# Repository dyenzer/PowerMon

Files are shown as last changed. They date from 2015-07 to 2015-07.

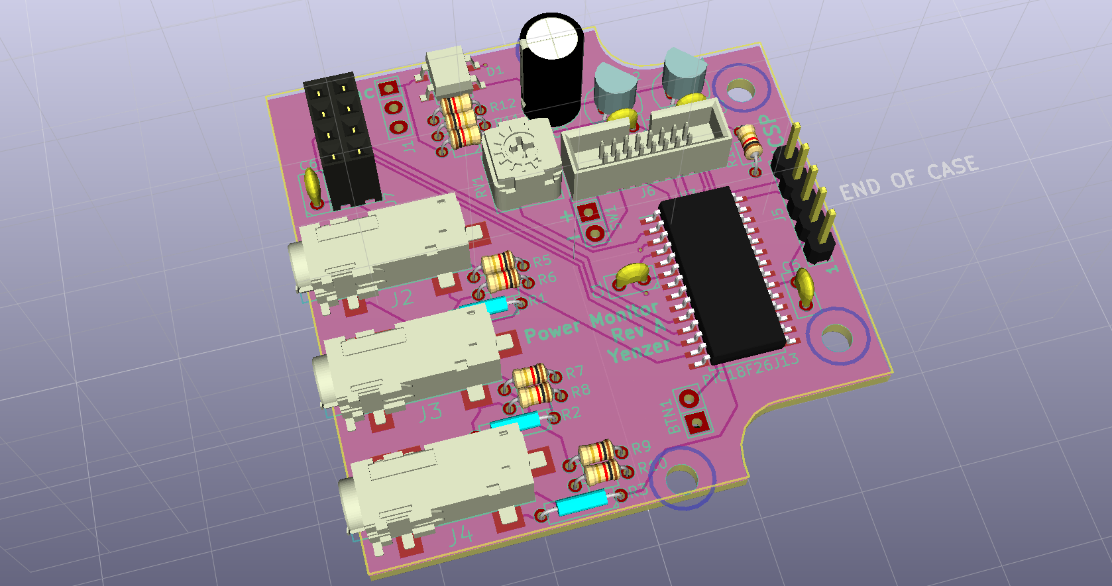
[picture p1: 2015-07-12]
Schematic/Power Monitor 3d.png

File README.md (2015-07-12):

#Power Monitor
Non-intrusive way to monitor the power consumed in your home

This repository contains the schematics and code for this project.
More details at https://hackaday.io/project/6700-home-power-usage-monitor
  
#Repository Contents
* **/Schematic** - Circuit diagram and PCB layout
  
#License Information
This project is released under <a href = "https://creativecommons.org/licenses/by-sa/4.0/">CC BY-SA 4.0</a>  
Original Design by Drew Yenzer

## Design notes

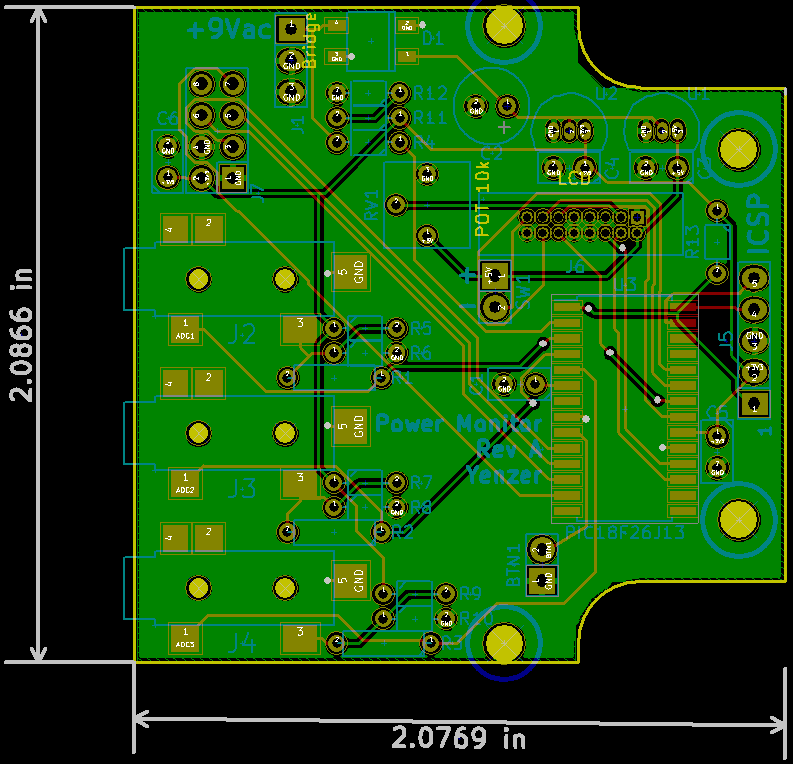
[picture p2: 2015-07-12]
Schematic/Board Layout.png

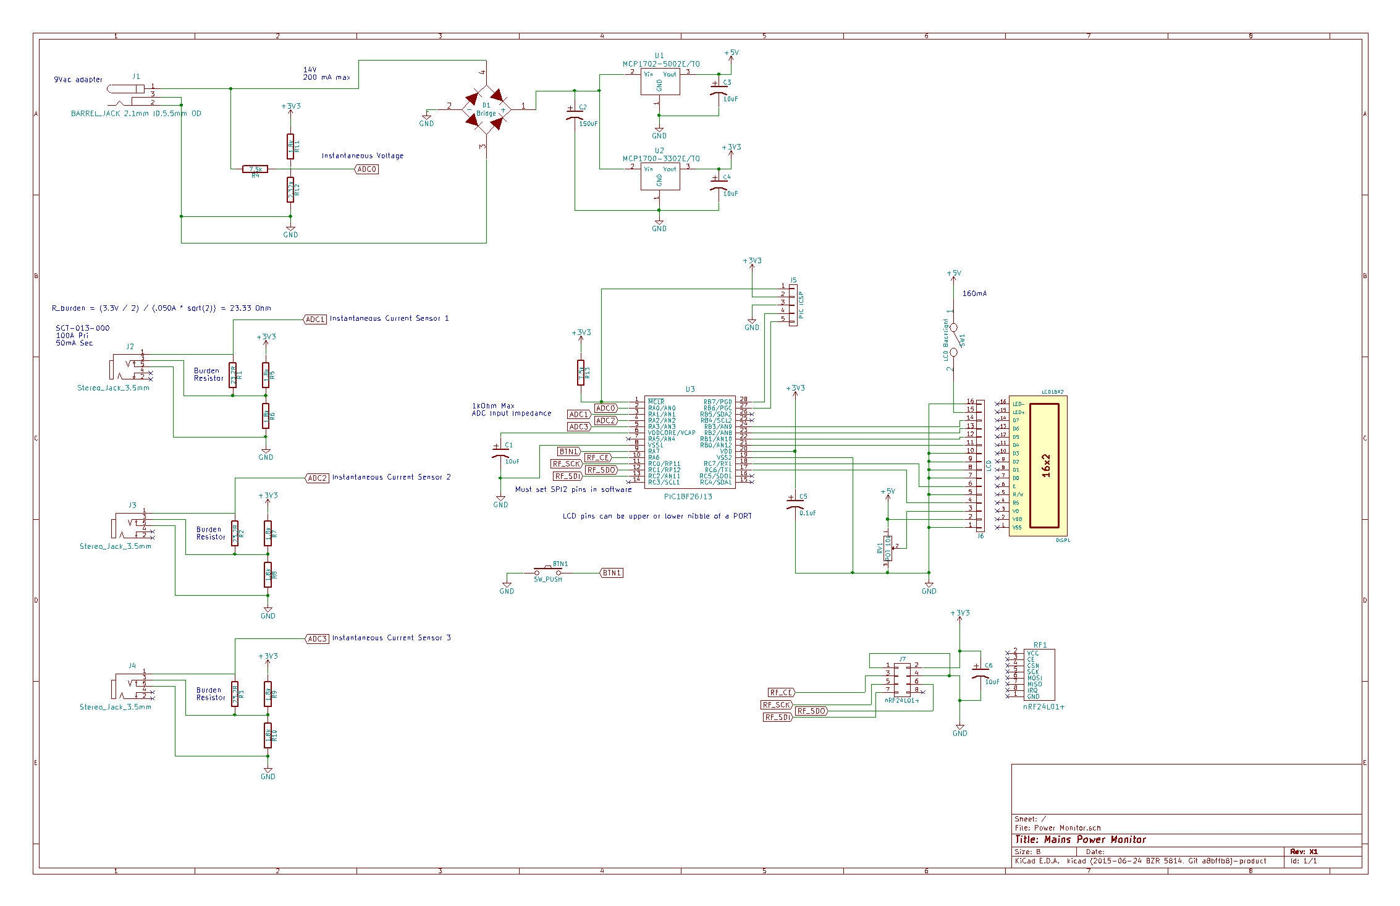
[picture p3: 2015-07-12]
Schematic/Schematic.png

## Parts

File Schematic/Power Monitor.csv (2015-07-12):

Source: | C:/Users/Drew/Desktop/Projects/Power Monitor/Schematic/Power Monitor.sch
Date: | 6/27/2015 16:34
Tool: | Eeschema (2015-06-24 BZR 5814, Git a8bffb8)-product
Generator: | C:\KiCad\bin\scripting\plugins\bom-in-python\bom_csv_grouped_by_value.py
Component Count: | 34
Individual Components:
Item | Qty | Reference(s) | Value | LibPart | Footprint | Datasheet
 |  | C1 | 10uF | device:CP1
 |  | C2 | 150uF | device:CP1
 |  | C3 | 10uF | device:CP1
 |  | C4 | 10uF | device:CP1
 |  | C5 | 0.1uF | device:CP1
 |  | C6 | 10uF | device:CP1
 |  | D1 | Bridge | custom:Bridge
 |  | DISP1 | LCD16X2 | display:LCD16X2 | WC1602A
 |  | J1 | BARREL_JACK 2.1mm ID,5.5mm OD | conn:BARREL_JACK
 |  | J2 | Stereo_Jack_3.5mm | custom:Stereo_Jack_3.5mm
 |  | J3 | Stereo_Jack_3.5mm | custom:Stereo_Jack_3.5mm
 |  | J4 | Stereo_Jack_3.5mm | custom:Stereo_Jack_3.5mm
 |  | J5 | PIC ICSP | conn:CONN_01X05
 |  | J6 | LCD | conn:CONN_01X16
 |  | J7 | nRF24L01+ | conn:CONN_02X04
 |  | R1 | 23.2R | device:R
 |  | R10 | 1.75k | device:R
 |  | R11 | 1.75k | device:R
 |  | R12 | 2.32k | device:R
 |  | R13 | 7.5k | device:R
 |  | R2 | 23.2R | device:R
 |  | R3 | 23.2R | device:R
 |  | R4 | 7.5k | device:R
 |  | R5 | 1.75k | device:R
 |  | R6 | 1.75k | device:R
 |  | R7 | 1.75k | device:R
 |  | R8 | 1.75k | device:R
 |  | R9 | 1.75k | device:R
 |  | RF1 | nRF24L01+ | custom:nRF24L01+
 |  | RV1 | POT 10k | device:POT
 |  | SW1 | LCD Backlight | device:SPST
 |  | U1 | MCP1702-5002E/TO | custom:MCP1700
 |  | U2 | MCP1700-3302E/TO | custom:MCP1700
 |  | U3 | PIC18F26J13 | custom:PIC18F2XJ13
Collated Components:
Item | Qty | Reference(s) | Value | LibPart | Footprint | Datasheet
1 | 4 | C1, C3, C4, C6 | 10uF | device:CP1
2 | 1 | C2 | 150uF | device:CP1
3 | 1 | C5 | 0.1uF | device:CP1
4 | 1 | D1 | Bridge | custom:Bridge
5 | 1 | DISP1 | LCD16X2 | display:LCD16X2 | WC1602A
6 | 1 | J1 | BARREL_JACK 2.1mm ID,5.5mm OD | conn:BARREL_JACK
7 | 3 | J2, J3, J4 | Stereo_Jack_3.5mm | custom:Stereo_Jack_3.5mm
8 | 1 | J5 | PIC ICSP | conn:CONN_01X05
9 | 1 | J6 | LCD | conn:CONN_01X16
10 | 1 | J7 | nRF24L01+ | conn:CONN_02X04
11 | 3 | R1, R2, R3 | 23.2R | device:R
12 | 7 | R10, R11, R5, R6, R7, R8, R9 | 1.75k | device:R
13 | 1 | R12 | 2.32k | device:R
14 | 2 | R13, R4 | 7.5k | device:R
15 | 1 | RF1 | nRF24L01+ | custom:nRF24L01+
16 | 1 | RV1 | POT 10k | device:POT
17 | 1 | SW1 | LCD Backlight | device:SPST
18 | 1 | U1 | MCP1702-5002E/TO | custom:MCP1700
19 | 1 | U2 | MCP1700-3302E/TO | custom:MCP1700
20 | 1 | U3 | PIC18F26J13 | custom:PIC18F2XJ13

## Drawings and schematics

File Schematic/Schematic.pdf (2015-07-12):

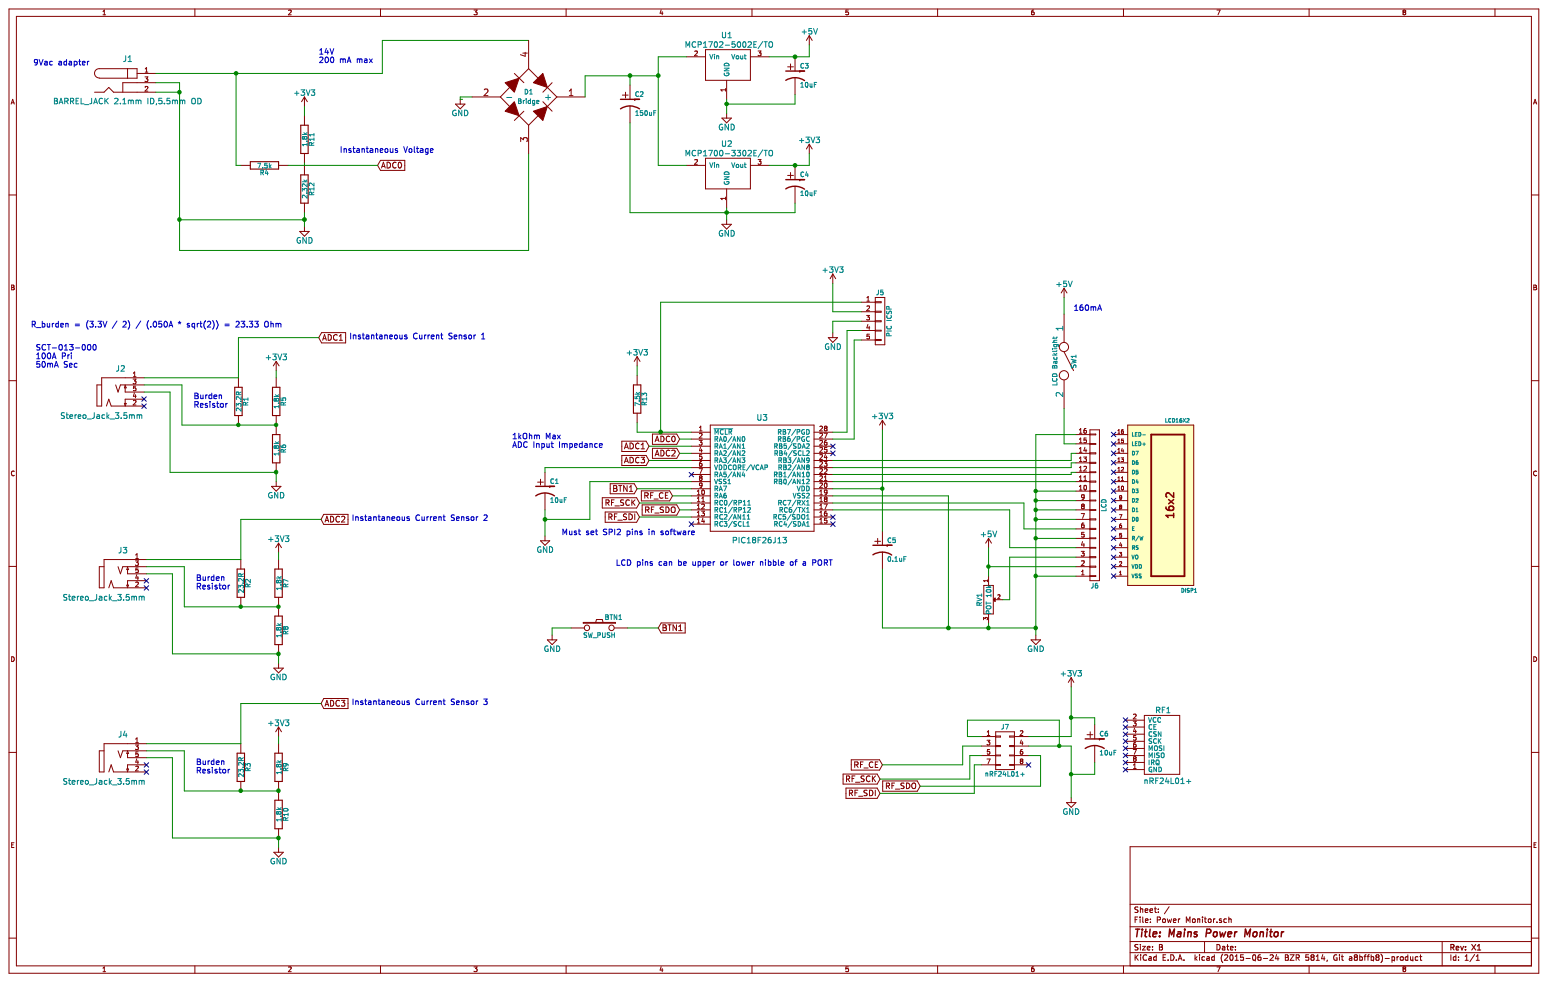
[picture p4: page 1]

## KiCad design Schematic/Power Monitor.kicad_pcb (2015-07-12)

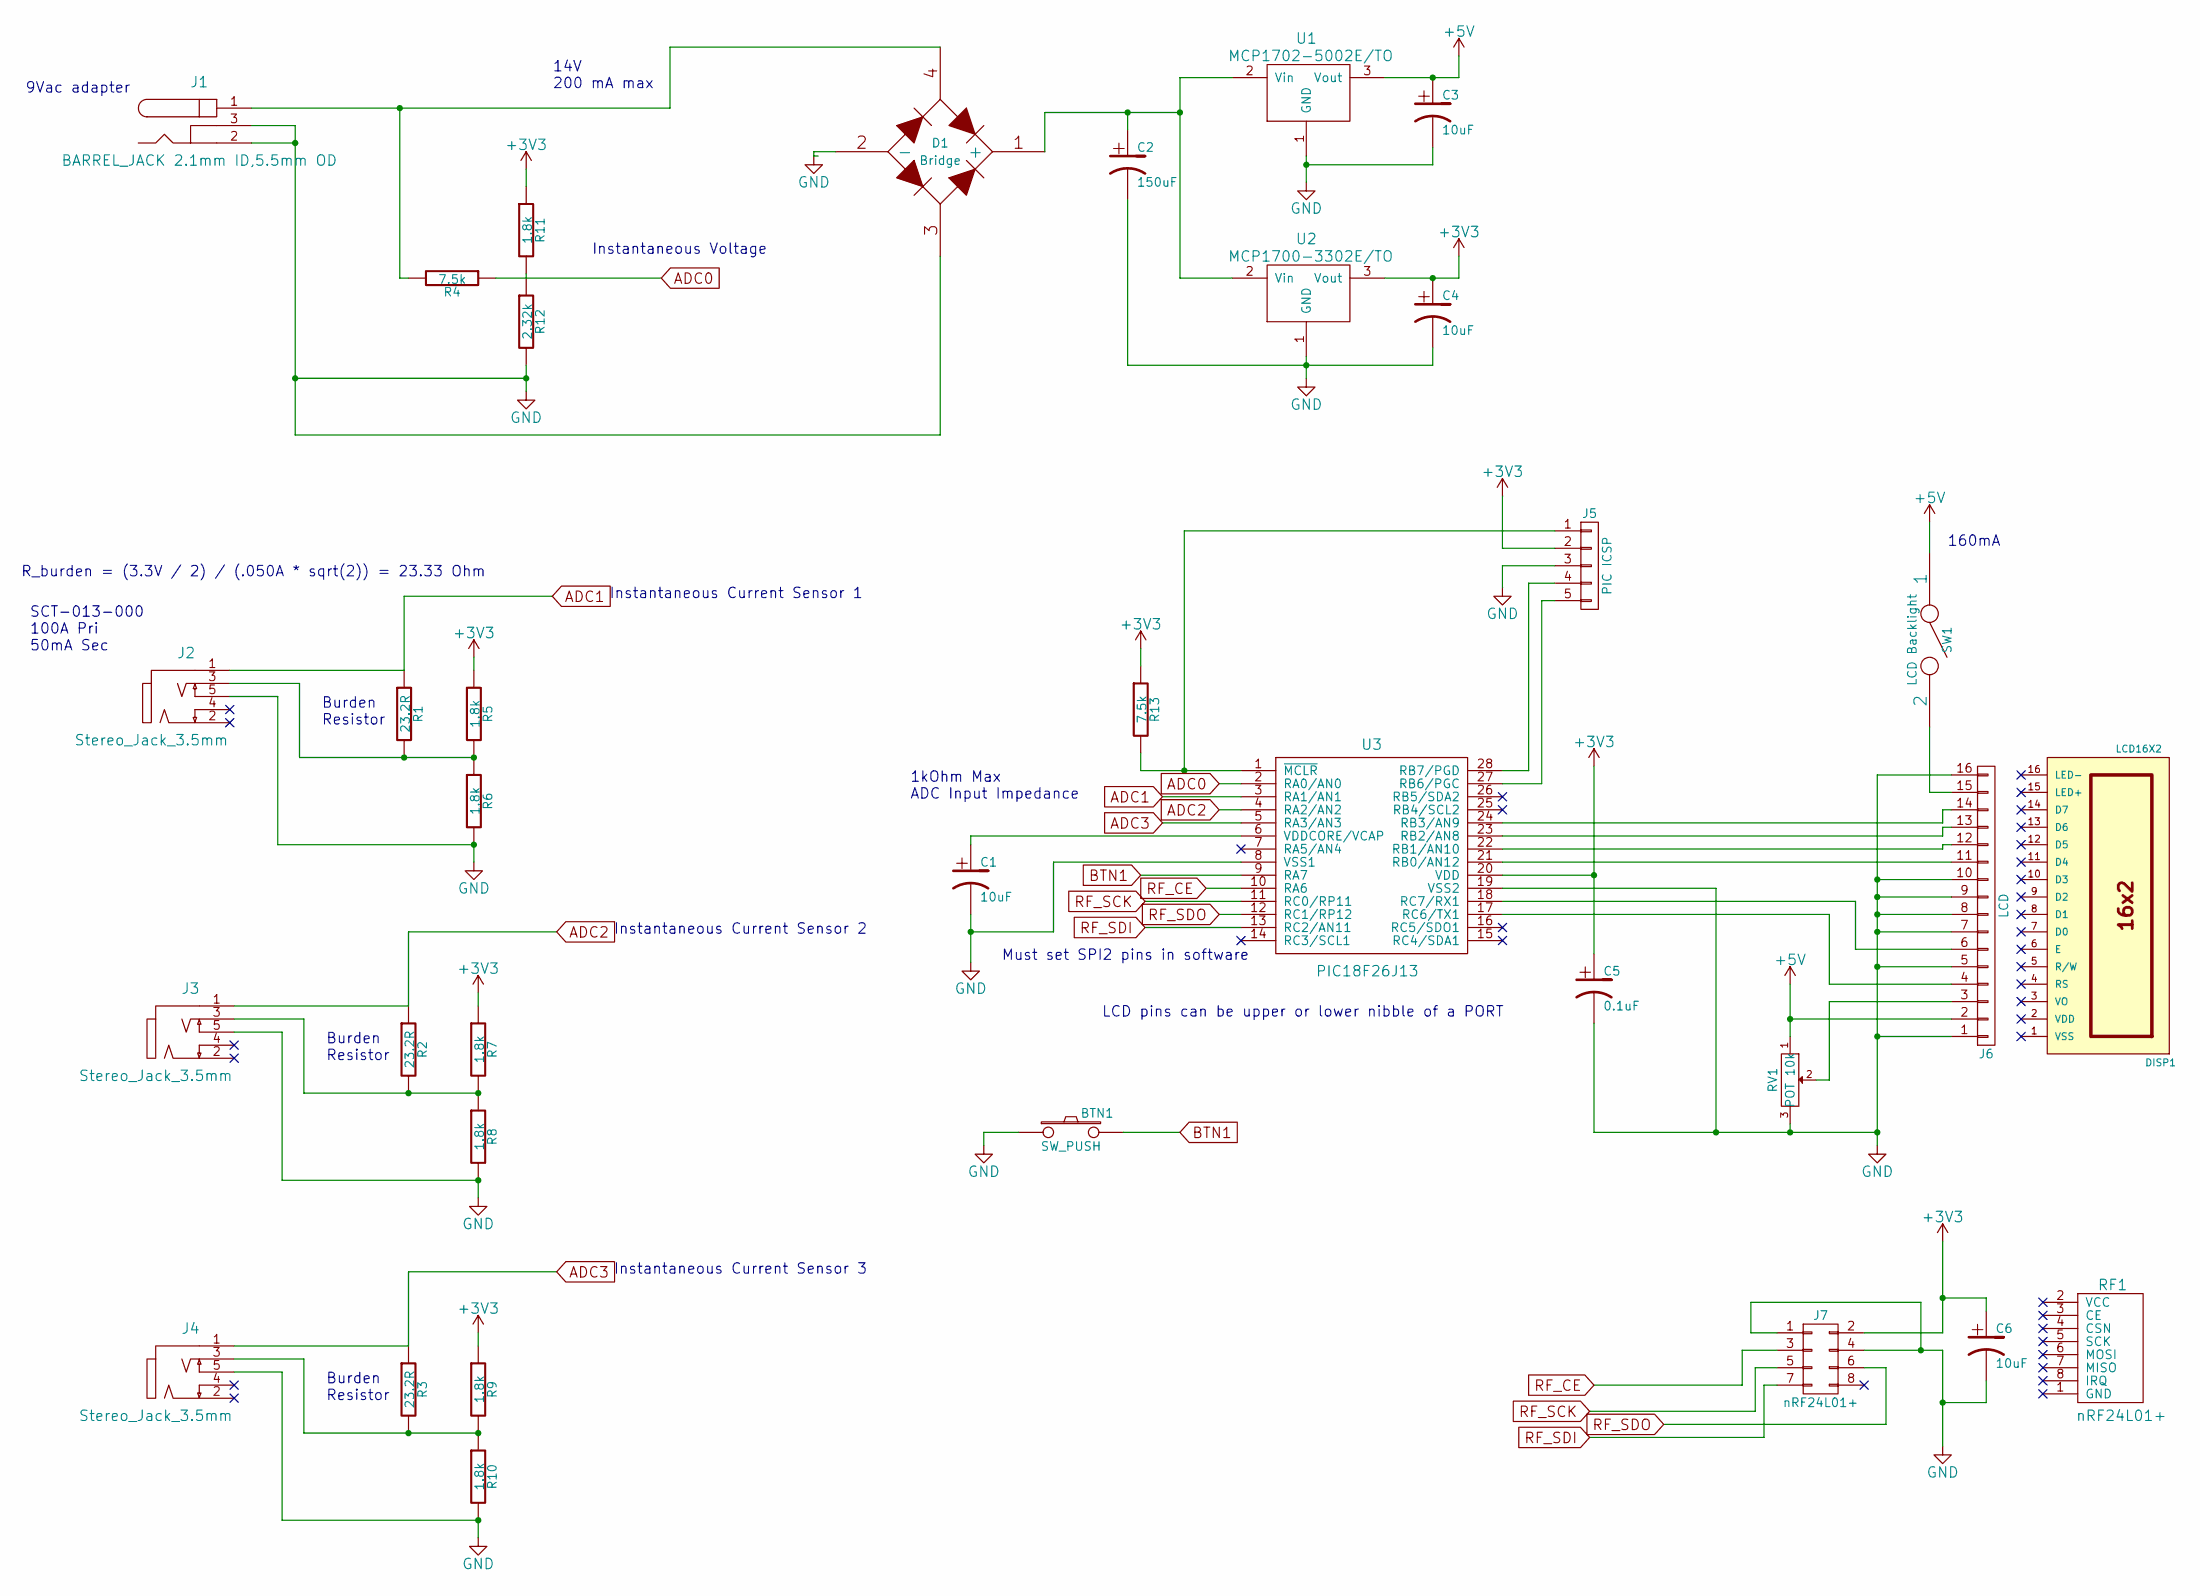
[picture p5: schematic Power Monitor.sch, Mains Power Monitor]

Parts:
BTN1: SW_PUSH; Pin_Header_Straight_1x02
C1, C3, C4, C6: 10uF; Capacitor3MMDiscRM2.5
C2: 150uF; Elko_vert_11.2x6.3mm_RM2.5
C5: 0.1uF; Capacitor3MMDiscRM2.5
D1: Bridge; Rectifier_SMT_TO-269AA
DISP1: LCD16X2; Dummy_Empty
J1: BARREL_JACK 2.1mm ID,5.5mm OD; Pin_Header_Straight_1x03
J2, J3, J4: Stereo_Jack_3.5mm; Stereo_Jack_3.5mm_2switch
J5: PIC ICSP; Pin_Header_Straight_1x05
J6: LCD; Conn_IDC_Header_TH_16pin
J7: nRF24L01+; Pin_Header_Straight_2x04
R1, R2, R3: 23.2R; R3
R4, R13: 7.5k; R2
R5, R6, R7, R8, R9, R10, R11: 1.8k; R2
R12: 2.32k; R2
RF1: nRF24L01+; Dummy_Empty
RV1: POT 10k; Potentiometer_Copal_CT-6EP
SW1: LCD Backlight; Pin_Header_Straight_1x02
U1: MCP1702-5002E/TO; TO-92-Free-inline-narrow-oval
U2: MCP1700-3302E/TO; TO-92-Free-inline-narrow-oval
U3: PIC18F26J13; SOIC-28_7.5x17.9mm_Pitch1.27mm

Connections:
+3V3: C4.1, C5.1, C6.1, J5.2, J7.2, R5.1, R7.1, R9.1, R11.1, R13.1, U2.3 (Vout), U3.20 (VDD)
+5V: C3.1, J6.2, RV1.1, SW1.1, U1.3 (Vout)
ADC0: R4.1, U3.2 (RA0/AN0)
ADC1: J2.1, R1.1, U3.3 (RA1/AN1)
ADC2: J3.1, R2.1, U3.4 (RA2/AN2)
ADC3: J4.1, R3.1, U3.5 (RA3/AN3)
BTN1: BTN1.2, U3.9 (RA7)
GND: BTN1.1, C1.2, C2.2, C3.2, C4.2, C5.2, C6.2, D1.2 (-), D1.3, J1.2, J1.3, J2.5, J3.5, J4.5, J5.3, J6.1, J6.5, J6.7, J6.8, J6.9, J6.10, J6.16, J7.1, J7.4, R6.2, R8.2, R10.2, R12.2, RV1.3, U1.1 (GND), U2.1 (GND), U3.8 (VSS1), U3.19 (VSS2)
unnamed: C1.1, U3.6 (VDDCORE/VCAP)
unnamed: C2.1, D1.1 (+), U1.2 (Vin), U2.2 (Vin)
unnamed: D1.4, J1.1, R4.2
unnamed: J2.3, R1.2, R5.2, R6.1
unnamed: J3.3, R2.2, R7.2, R8.1
unnamed: J4.3, R3.2, R9.2, R10.1
unnamed: J5.1, R13.2, U3.1 (~MCLR)
unnamed: J5.4, U3.28 (RB7/PGD)
unnamed: J5.5, U3.27 (RB6/PGC)
unnamed: J6.3, RV1.2
unnamed: J6.4, U3.17 (RC6/TX1)
unnamed: J6.6, U3.18 (RC7/RX1)
unnamed: J6.11, U3.21 (RB0/AN12)
unnamed: J6.12, U3.22 (RB1/AN10)
unnamed: J6.13, U3.23 (RB2/AN8)
unnamed: J6.14, U3.24 (RB3/AN9)
unnamed: J6.15, SW1.2
unnamed: R11.2, R12.1
RF_CE: J7.3, U3.10 (RA6)
RF_SCK: J7.5, U3.11 (RC0/RP11)
RF_SDI: J7.7, U3.13 (RC2/AN11)
RF_SDO: J7.6, U3.12 (RC1/RP12)

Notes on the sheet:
Burden Resistor
SCT-013-000 100A Pri 50mA Sec
R_burden = (3.3V / 2) / (.050A * sqrt(2)) = 23.33 Ohm
Must set SPI2 pins in software
LCD pins can be upper or lower nibble of a PORT
Instantaneous Voltage
Instantaneous Current Sensor 1
Instantaneous Current Sensor 2
Instantaneous Current Sensor 3
9Vac adapter
14V 200 mA max
160mA
1kOhm Max ADC Input Impedance

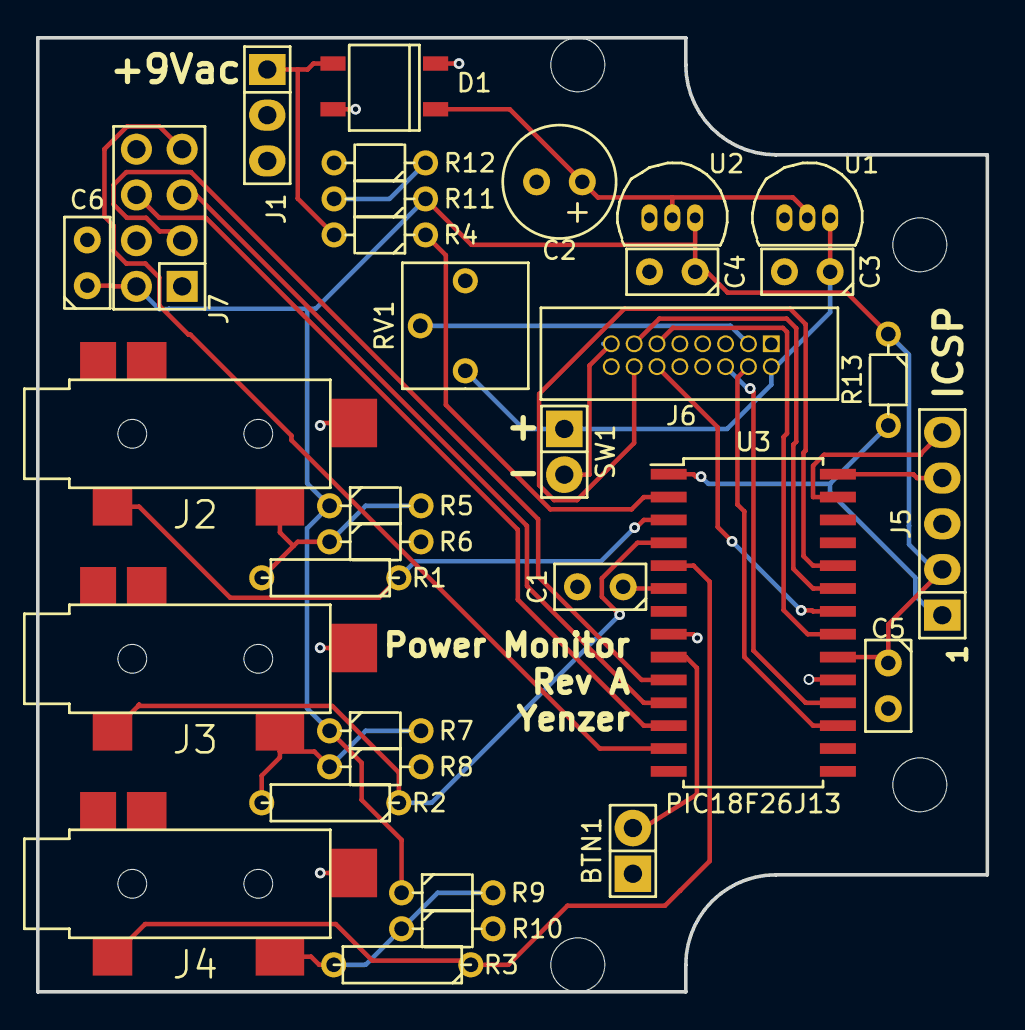
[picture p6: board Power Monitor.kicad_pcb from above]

Board: 2 copper layers, 52.8 x 53.0 mm, 37 parts (0 on the bottom side), 30 nets.

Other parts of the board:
MountingHole1, MountingHole2, MountingHole3, MountingHole4: VAL**; MountingHole_3mm
